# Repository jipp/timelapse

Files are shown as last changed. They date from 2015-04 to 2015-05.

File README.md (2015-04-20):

# timelapse
ATtiny 2313 based timelapse controller.

## The following features are implemented
* 10 programs to select different time intervals
* 7-segment LED will be disabled after some time and reenabled after pressing button showing the lastest selected program
* selected program will be stored in EEPROM

## Installation
Put the timelapse folder into the local Arduino folder.

## Additional files
EAGLE files included:
* Circuit diagram
* Board layout

## Info
This was developed 1st for a Nikon, but as a 2.5mm Jack is used to connect the camera any camera adapter should work.

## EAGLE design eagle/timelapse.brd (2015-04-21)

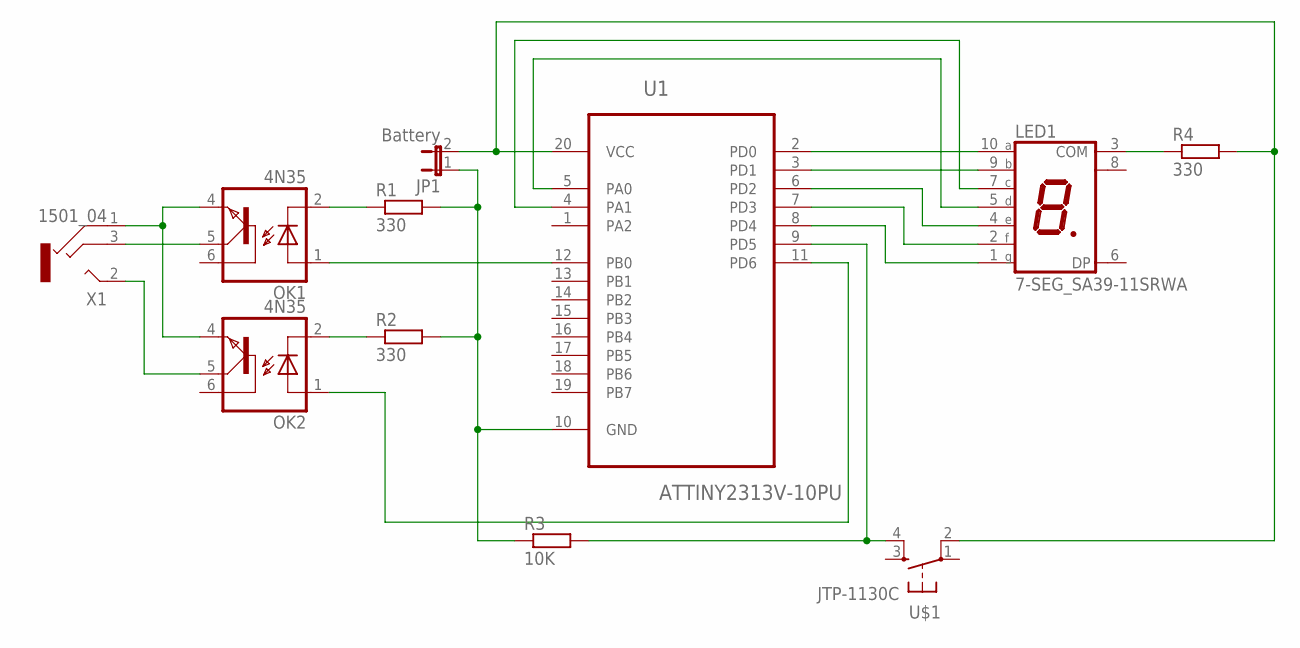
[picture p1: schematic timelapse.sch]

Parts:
JP1: Battery; JP1
LED1: 7-SEG_SA39-11SRWA; SA39-11SRWA
OK1, OK2: 4N35; DIL06
R1, R2, R4: 330; 0204/7
R3: 10K; 0204/7
U1: ATTINY2313V-10PU; DIP254P762X533-20
U$1: JTP-1130C; JTP-1130
X1: 1501_04; 1501_05

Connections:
unnamed: LED1.10 (A), U1.2 (PD0)
unnamed: LED1.9 (B), U1.3 (PD1)
unnamed: LED1.4 (E), U1.6 (PD2)
unnamed: LED1.2 (F), U1.7 (PD3)
unnamed: LED1.1 (G), U1.8 (PD4)
unnamed: LED1.7 (C), U1.4 (PA1)
unnamed: LED1.5 (D), U1.5 (PA0)
unnamed: LED1.3 (COM), R4.1
unnamed: JP1.2, R4.2, U1.20 (VCC), U$1.2 (P1)
unnamed: R3.2, U1.9 (PD5), U$1.4 (S1)
unnamed: JP1.1, R1.2, R2.2, R3.1, U1.10 (GND)
unnamed: OK2.1 (A), U1.11 (PD6)
unnamed: OK2.2 (C), R2.1
unnamed: OK1.2 (C), R1.1
unnamed: OK1.1 (A), U1.12 (PB0)
unnamed: OK1.4 (EMI), OK2.4 (EMI), X1.1
unnamed: OK1.5 (COL), X1.3
unnamed: OK2.5 (COL), X1.2

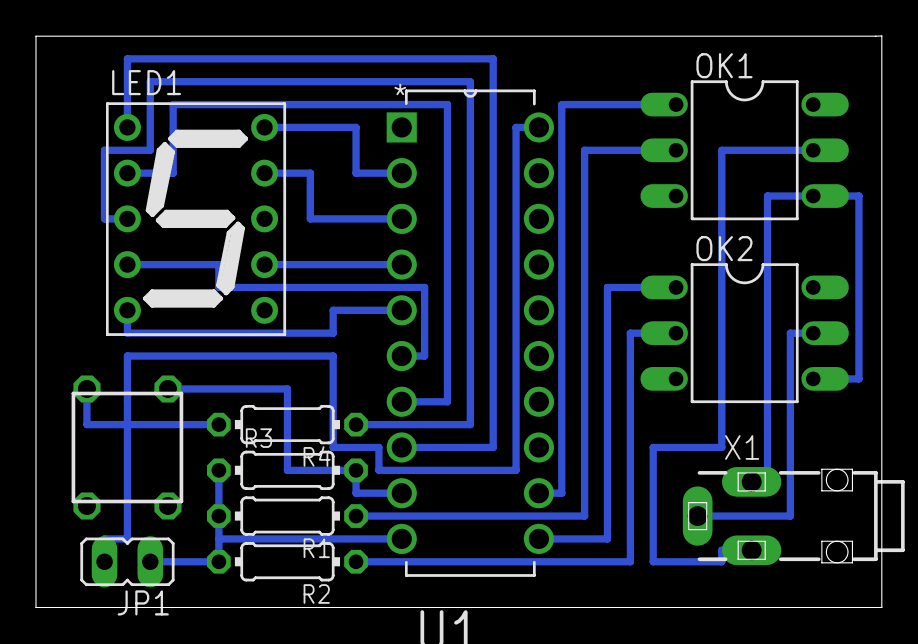
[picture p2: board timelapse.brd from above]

Board: 2 copper layers, 47.0 x 31.8 mm, 11 parts (0 on the bottom side), 18 nets.

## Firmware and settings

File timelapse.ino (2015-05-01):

#include <EEPROM.h>

// 7 segments -> pin#
#define a 0
#define b 1
#define c 2
#define d 3
#define e 4
#define f 5
#define g 6

// button for program select
#define button 7

// DSLR focus and shutter
#define focus 8
#define shutter 9

// store program in EEPROM
const byte address = 0;

// duration of 7 segment light on
const byte ledOn = 5;

// initialize variable
bool buttonState = false;
byte program = 0;
bool pressed = false;
bool ledState = false;
unsigned long ledShine = 0L;
unsigned long shootTime = 0L;

// program# -> length
byte programs[] = { 1, 2, 3, 4, 5, 6, 7, 8, 9, 10 };

// # of programs
const byte programLimit = sizeof(programs) / sizeof(programs[0]) - 1;

void setup() {
	pinMode(a, OUTPUT);
	pinMode(b, OUTPUT);
	pinMode(c, OUTPUT);
	pinMode(d, OUTPUT);
	pinMode(e, OUTPUT);
	pinMode(f, OUTPUT);
	pinMode(g, OUTPUT);

	pinMode(focus, OUTPUT);
	pinMode(shutter, OUTPUT);

	pinMode(button, INPUT);

	program = EEPROM.read(address);

	// clean display
	sevenSegWrite(10);
	digitalWrite(focus, LOW);
	digitalWrite(shutter, LOW);
}

void loop() {
	buttonState = digitalRead(button);

	if (ledState && buttonState && !pressed) {
		if (program++ >= programLimit) {
			program = 0;
		}
		ledShine = millis();
		pressed = true;
		EEPROM.write(address, program);
		sevenSegWrite(program);
		delay(100);
	}
	if (ledState && pressed && !buttonState) {
		pressed = false;
	}
	if (!ledState && !pressed && buttonState) {
		ledShine = millis();
		ledState = true;
		pressed = true;
		sevenSegWrite(program);
	}
	if (ledState && (millis() > ledShine + ledOn * 1000)) {
		ledState = false;
		pressed = false;
		sevenSegWrite(10);
	}
	if (millis() > shootTime + programs[program] * 1000) {
		shootTime = millis();
		shoot();
	}
}

void shoot() {
	digitalWrite(focus, HIGH);
	delay(100);
	digitalWrite(shutter, HIGH);
	delay(250);
	digitalWrite(shutter, LOW);
	digitalWrite(focus, LOW);
}

// either high memory or more program lines - you pay for one with the other
void sevenSegWrite(byte digit) {
	switch (digit) {
	case 1:
		digitalWrite(a, true);
		digitalWrite(b, false);
		digitalWrite(c, false);
		digitalWrite(d, true);
		digitalWrite(e, true);
		digitalWrite(f, true);
		digitalWrite(g, true);
		break;
	case 2:
		digitalWrite(a, false);
		digitalWrite(b, false);
		digitalWrite(c, true);
		digitalWrite(d, false);
		digitalWrite(e, false);
		digitalWrite(f, true);
		digitalWrite(g, false);
		break;
	case 3:
		digitalWrite(a, false);
		digitalWrite(b, false);
		digitalWrite(c, false);
		digitalWrite(d, false);
		digitalWrite(e, true);
		digitalWrite(f, true);
		digitalWrite(g, false);
		break;
	case 4:
		digitalWrite(a, true);
		digitalWrite(b, false);
		digitalWrite(c, false);
		digitalWrite(d, true);
		digitalWrite(e, true);
		digitalWrite(f, false);
		digitalWrite(g, false);
		break;
	case 5:
		digitalWrite(a, false);
		digitalWrite(b, true);
		digitalWrite(c, false);
		digitalWrite(d, false);
		digitalWrite(e, true);
		digitalWrite(f, false);
		digitalWrite(g, false);
		break;
	case 6:
		digitalWrite(a, false);
		digitalWrite(b, true);
		digitalWrite(c, false);
		digitalWrite(d, false);
		digitalWrite(e, false);
		digitalWrite(f, false);
		digitalWrite(g, false);
		break;
	case 7:
		digitalWrite(a, false);
		digitalWrite(b, false);
		digitalWrite(c, false);
		digitalWrite(d, true);
		digitalWrite(e, true);
		digitalWrite(f, true);
		digitalWrite(g, true);
		break;
	case 8:
		digitalWrite(a, false);
		digitalWrite(b, false);
		digitalWrite(c, false);
		digitalWrite(d, false);
		digitalWrite(e, false);
		digitalWrite(f, false);
		digitalWrite(g, false);
		break;
	case 9:
		digitalWrite(a, false);
		digitalWrite(b, false);
		digitalWrite(c, false);
		digitalWrite(d, true);
		digitalWrite(e, true);
		digitalWrite(f, false);
		digitalWrite(g, false);
		break;
	case 0:
		digitalWrite(a, false);
		digitalWrite(b, false);
		digitalWrite(c, false);
		digitalWrite(d, false);
		digitalWrite(e, false);
		digitalWrite(f, false);
		digitalWrite(g, true);
		break;
	default:
		digitalWrite(a, true);
		digitalWrite(b, true);
		digitalWrite(c, true);
		digitalWrite(d, true);
		digitalWrite(e, true);
		digitalWrite(f, true);
		digitalWrite(g, true);
		break;
	}
}

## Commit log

2015-04-12 introduce pin for shutter and focus
2015-04-16 bug fixes button and "3" not correct
    [timelapse.ino]
2015-04-16 fixed the "3" again
    [timelapse.ino]
2015-04-19 add EAGLE files
    [Timelapse.brd, Timelapse.sch]
2015-04-20 changed 3mm -> 2.5mm
2015-04-20 updated eagle with small changes
    -move jumper
    -rearrange diagram
    [Timelapse.brd, Timelapse.sch]
2015-04-21 change of board layout - smaller
    [timelapse .brd, timelapse .sch]
2015-04-21 rename of files
    [timelapse.brd, timelapse.sch]
2015-05-01 remove include for Arduino.h
